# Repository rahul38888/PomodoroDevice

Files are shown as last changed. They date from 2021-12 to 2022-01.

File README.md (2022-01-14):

# PomodoroDevice

## 7 segments leds

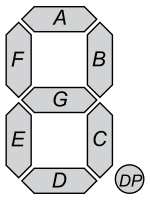
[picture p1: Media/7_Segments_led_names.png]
7 segments led names


## 4x7 segment display pinout diagram

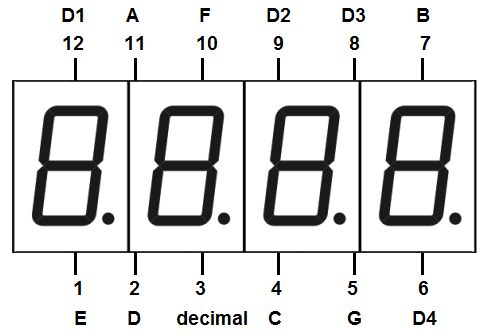
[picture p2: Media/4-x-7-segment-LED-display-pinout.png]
4x7 segment display pinout diagram


## Shift register 74HC595

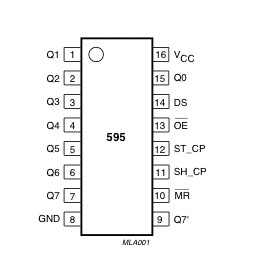
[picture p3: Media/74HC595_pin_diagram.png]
Shift register 74HC595


## Pins connections
| 4x7 pins | Arduino pins |
|-|-|
|D1 (Through 220 Ω)|2|
|D2 (Through 220 Ω)|3|
|D3 (Through 220 Ω)|4|
|D4 (Through 220 Ω)|5|

| 4x7 pins | 74HC595 pins |
|-|-|
|A|Q0|
|B|Q1|
|C|Q2|
|D|Q3|
|E|Q4|
|F|Q5|
|G|Q6|
|DP|Q7|

| Arduino pins | 74HC595 pins |
|-|-|
|GND|GND|
|5V|Vcc|
|11|DS|
|GND|OE|
|8|ST_CP|
|12|SH_CP|
|5V|MR|

## Bytes to Character mapping
|Character|Byte value (ABCDEFG)|Integer value|
|-|-|-|
|0|0000001|1|
|1|1001111|79|
|2|0010010|18|
|3|0000110|6|
|4|1001100|76|
|5|0100100|36|
|6|0100000|32|
|7|0001111|15|
|8|0000000|0|
|9|0000100|4|
|Blacnk|1111111|127|

1 means inactive and 0 means active.

**74HC595** need to have 8 bits written into it. The 1st place bit will decide state of **DP**. That is being added on runtime.

## Circuit diagrams
Schematics

## 3D plates

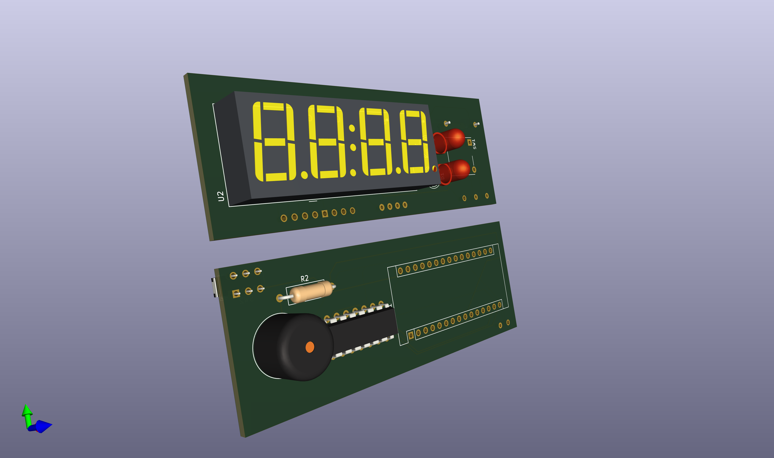
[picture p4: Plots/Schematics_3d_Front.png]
3D plates Front


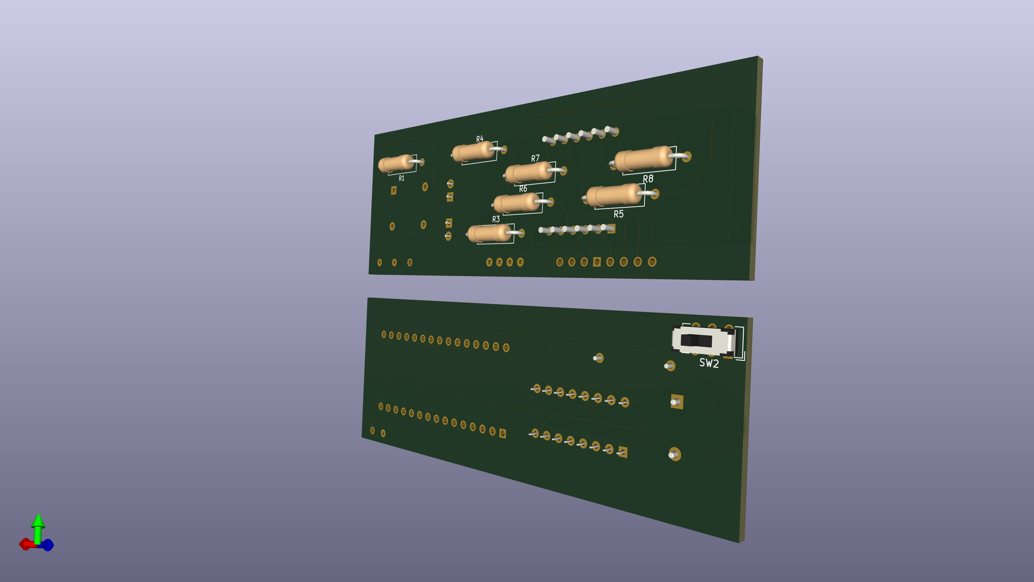
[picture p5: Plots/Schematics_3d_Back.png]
3D plates Back


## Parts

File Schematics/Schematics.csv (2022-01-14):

Source: | /Users/rpanchal/m_pro/Arduinos/PomodoroDevice/Schematics/Schematics.kicad_sch
Date: | 2022 January 02, Sunday 22:37:07
Tool: | Eeschema (6.0.0-0)
Generator: | /Applications/KiCad/KiCad.app/Contents/SharedSupport/plugins/bom_csv_grouped_by_value_with_fp.py
Component Count: | 15
Ref | Qnty | Value | Cmp name | Footprint | Description | Vendor
A1, | 1 | Arduino_Nano_v3.x | Arduino_Nano_v3.x | Module:Arduino_Nano | Arduino Nano v3.x
BZ1, | 1 | Buzzer | Buzzer | Buzzer_Beeper:Buzzer_12x9.5RM7.6 | Buzzer, polarized
D1, | 1 | Green LED | LED | LED_THT:LED_D5.0mm | Light emitting diode
D2, | 1 | Orange LED | LED | LED_THT:LED_D5.0mm | Light emitting diode
R1, R3, R4, R5, R6, R7, R8, | 7 | R 220 | R_Small | Resistor_THT:R_Axial_DIN0309_L9.0mm_D3.2mm_P12.70mm_Horizontal | Resistor, small symbol
R2, | 1 | R 100 | R_Small | Resistor_THT:R_Axial_DIN0309_L9.0mm_D3.2mm_P12.70mm_Horizontal | Resistor, small symbol
SW1, | 1 | SW_MEC_5E | SW_MEC_5E | Button_Switch_THT:SW_MEC_5GTH9 | MEC 5E single pole normally-open tactile switch
U1, | 1 | 74HC595 | 74HC595 | Package_DIP:DIP-16_W7.62mm | 8-bit serial in/out Shift Register 3-State Outputs
U2, | 1 | CC56-12YWA | CC56-12YWA | Display_7Segment:CC56-12YWA | 4 digit 7 segment yellow LED, common cathode

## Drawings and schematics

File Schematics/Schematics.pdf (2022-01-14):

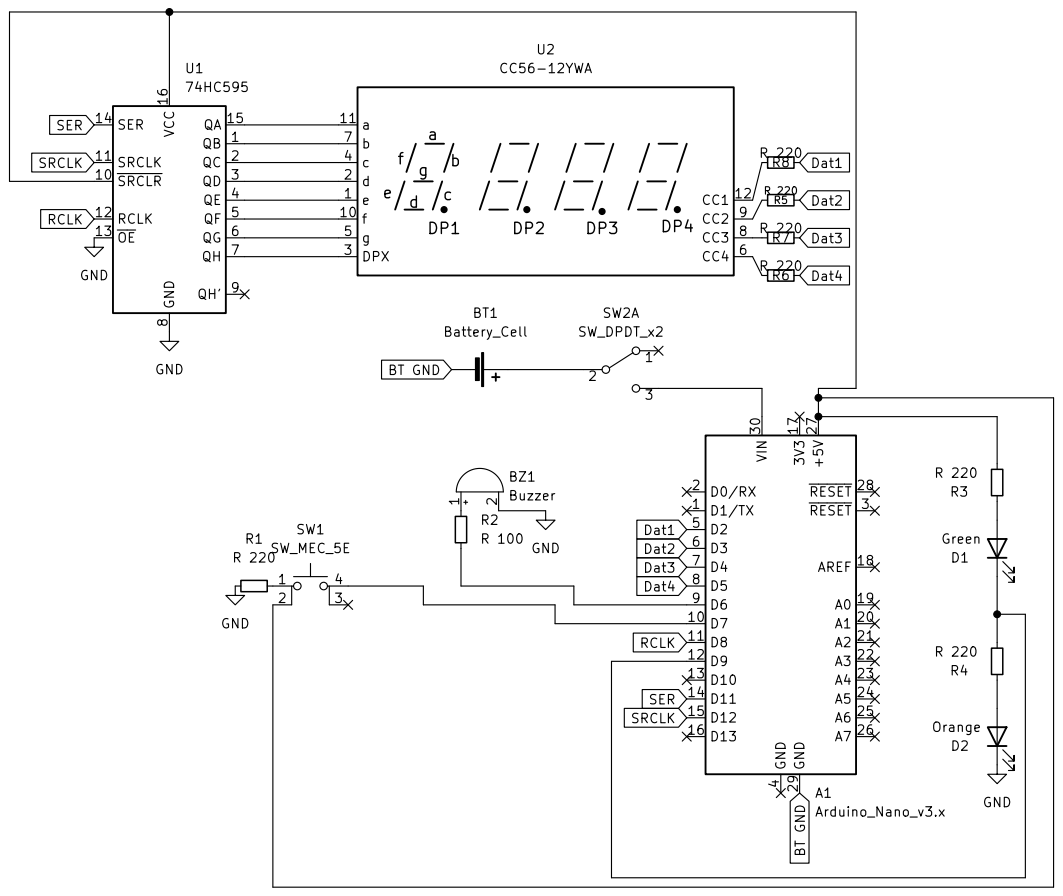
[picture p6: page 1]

File: Schematics.kicad_sch Sheet: / R1 R 220 GND

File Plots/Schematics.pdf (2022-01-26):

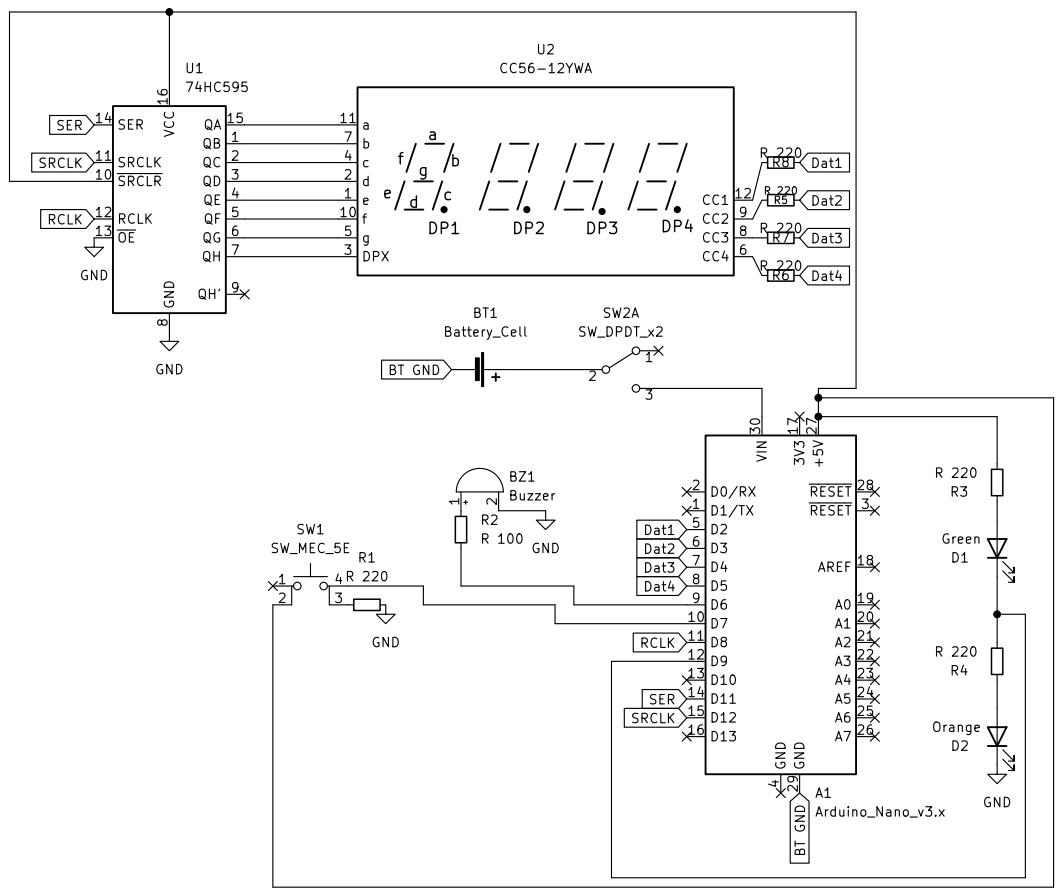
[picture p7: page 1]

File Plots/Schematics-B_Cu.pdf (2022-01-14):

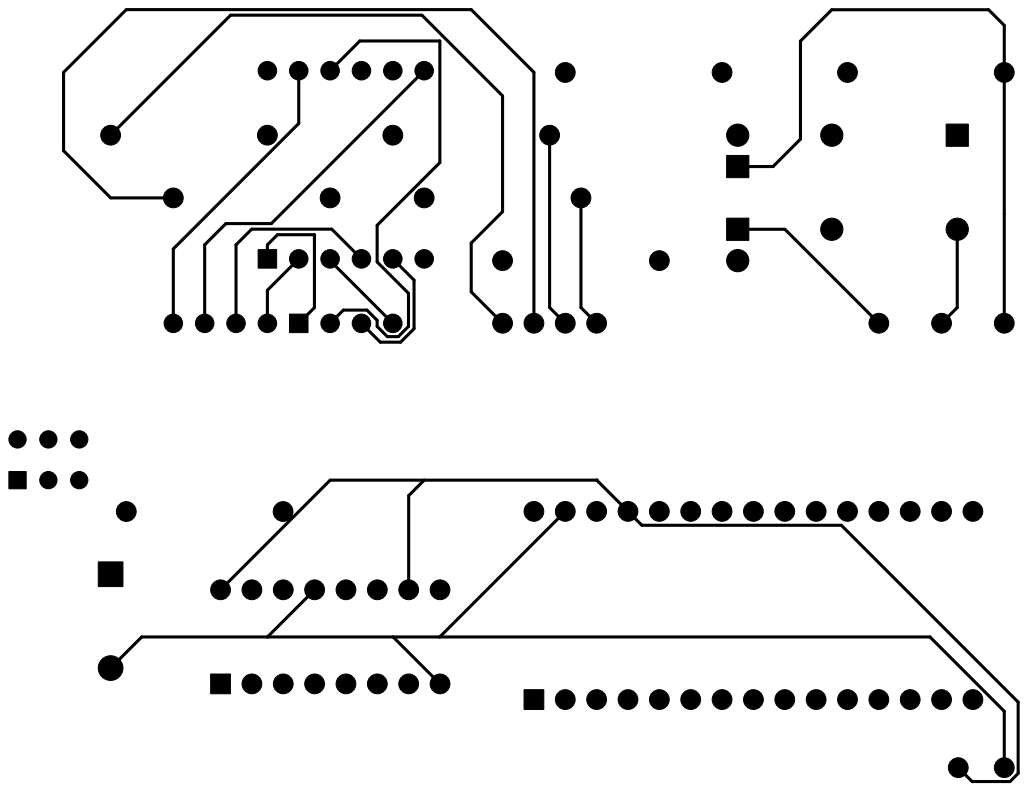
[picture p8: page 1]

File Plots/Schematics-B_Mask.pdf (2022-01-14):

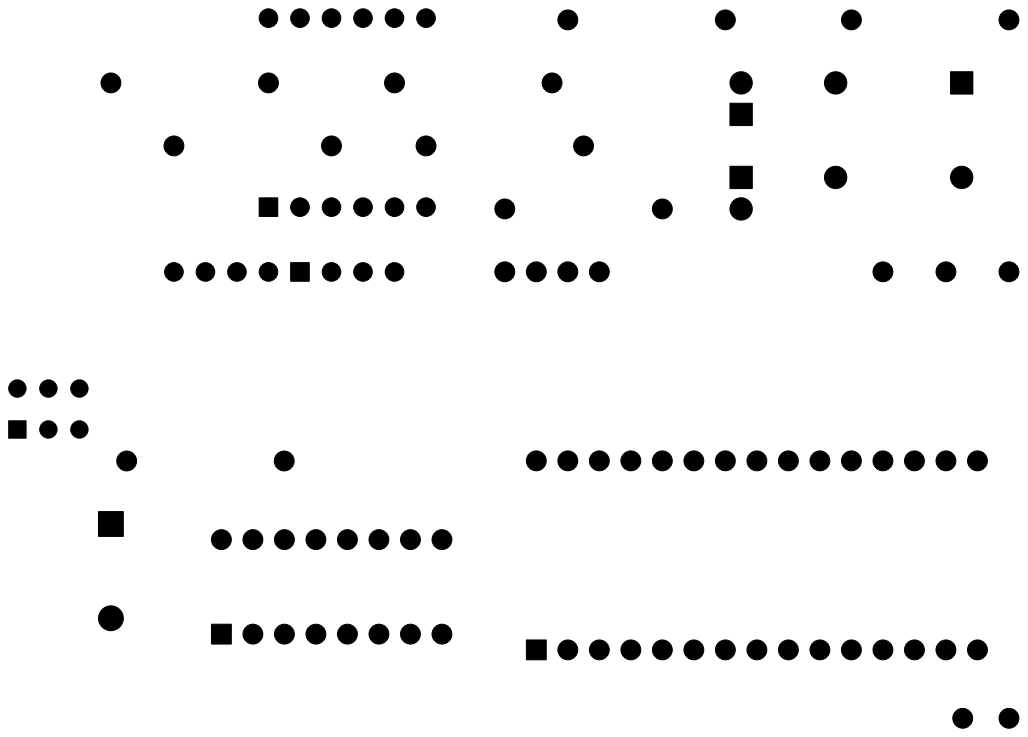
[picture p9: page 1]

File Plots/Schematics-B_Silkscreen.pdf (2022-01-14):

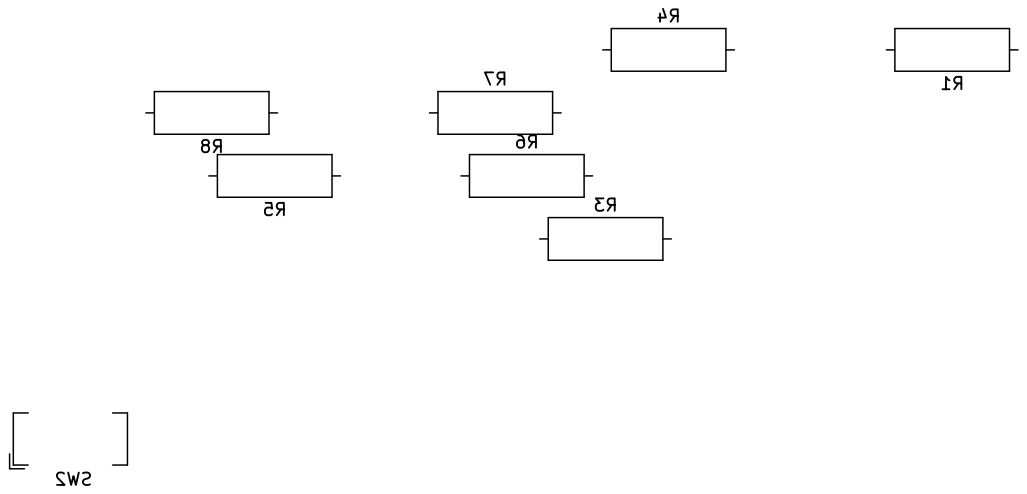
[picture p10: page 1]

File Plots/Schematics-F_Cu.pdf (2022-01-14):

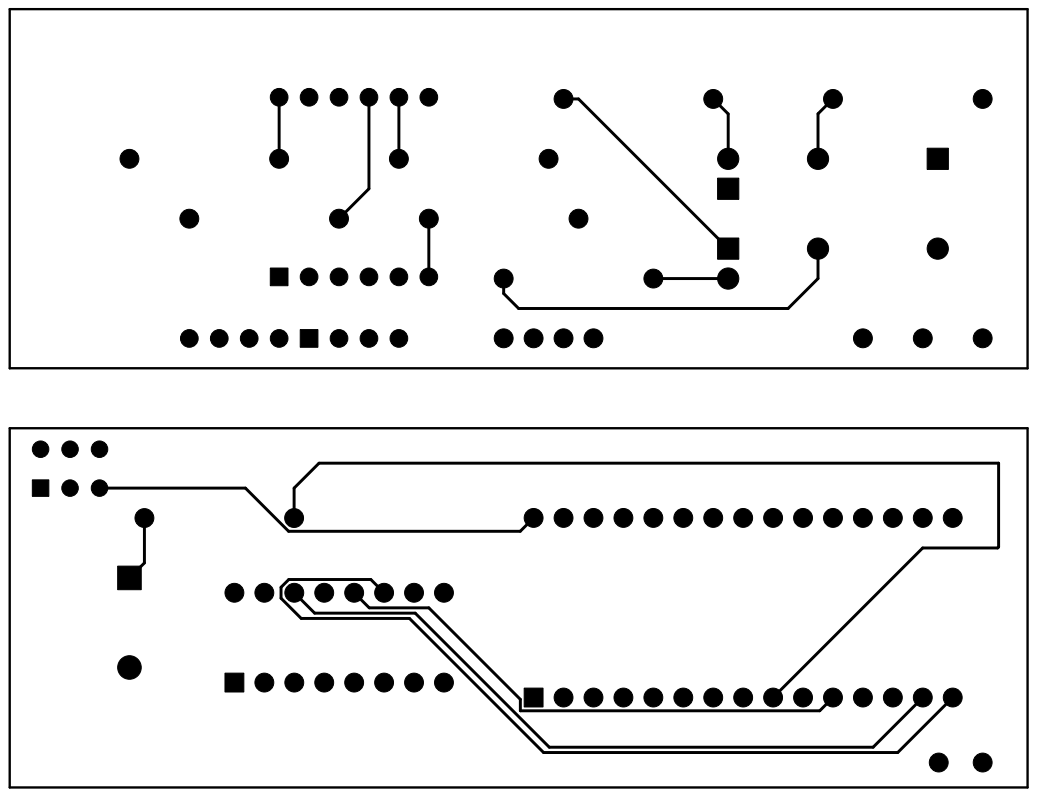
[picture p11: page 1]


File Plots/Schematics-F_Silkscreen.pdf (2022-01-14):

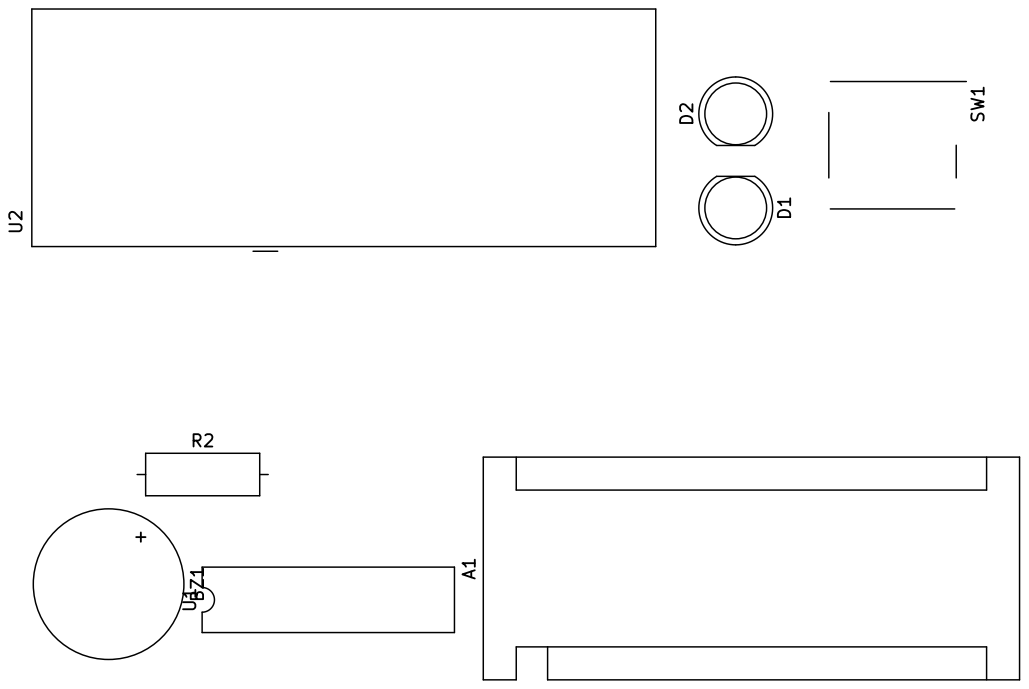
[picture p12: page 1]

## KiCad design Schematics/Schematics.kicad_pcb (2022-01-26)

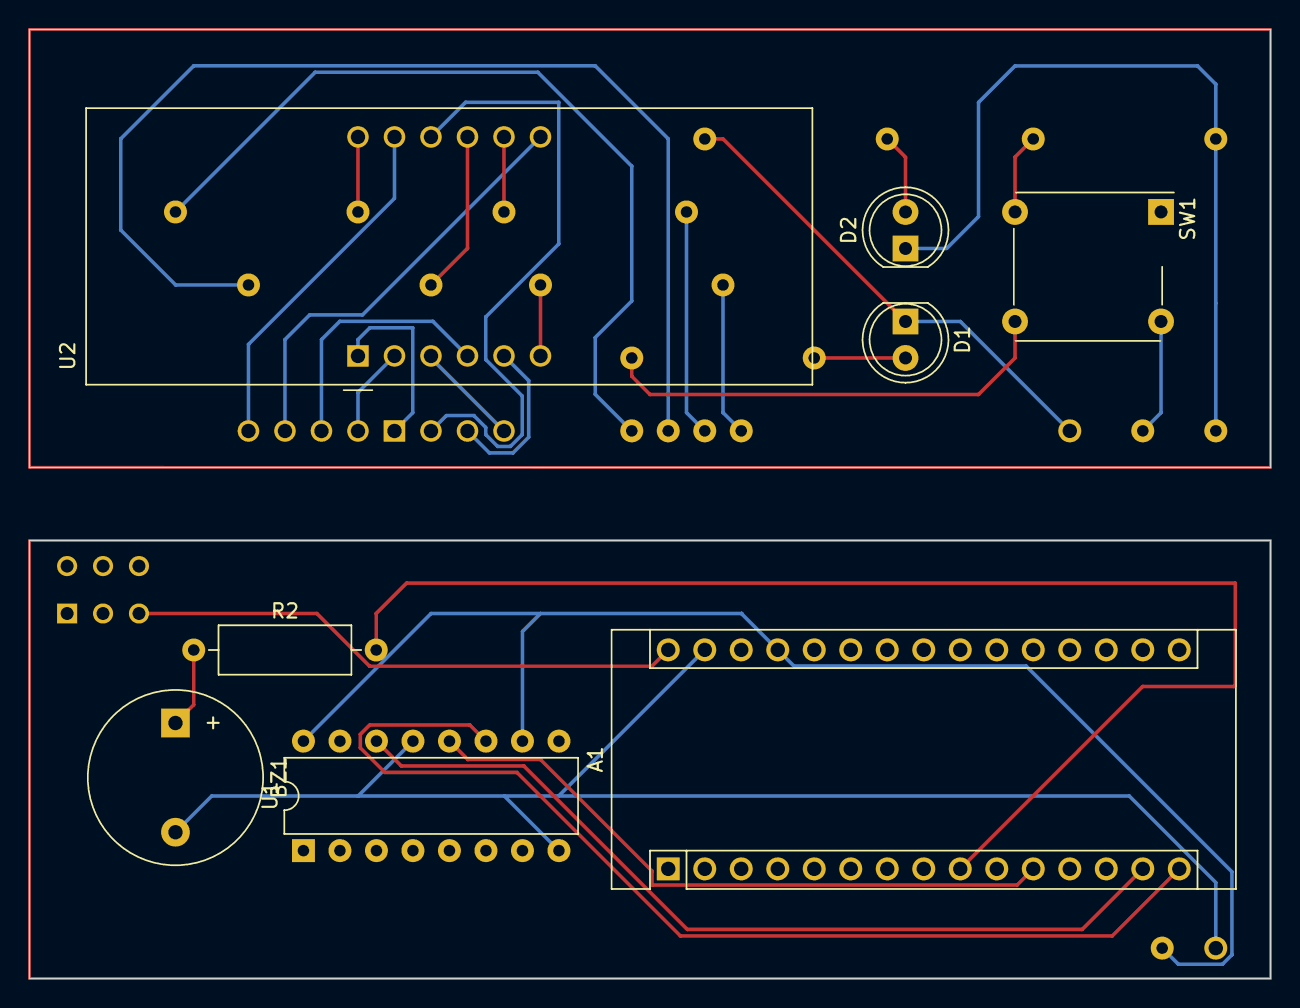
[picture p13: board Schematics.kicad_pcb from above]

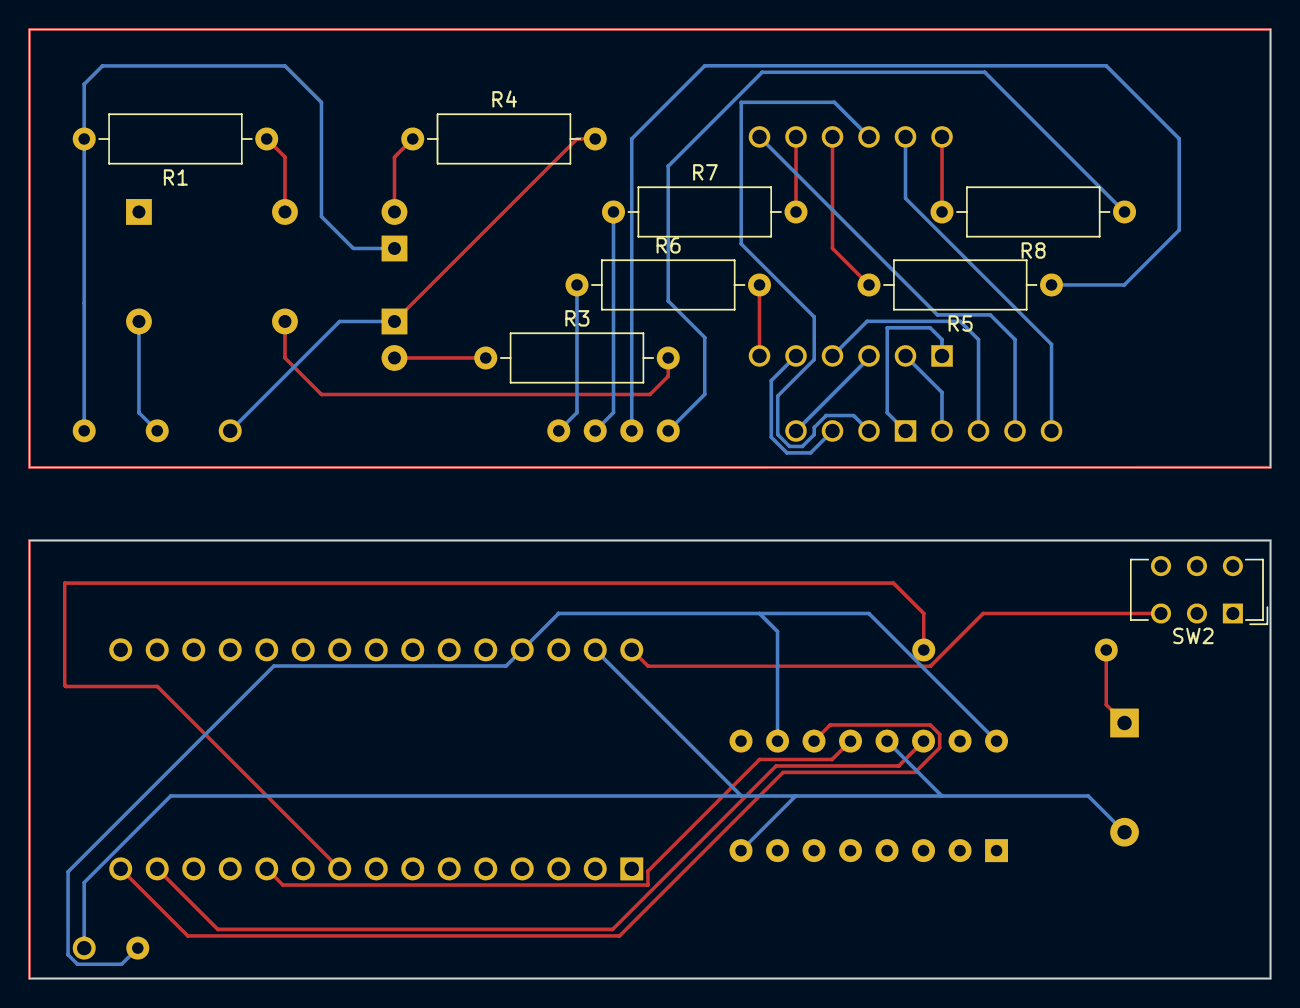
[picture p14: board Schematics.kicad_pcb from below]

Board: 2 copper layers, 86.4 x 66.0 mm, 16 parts (8 on the bottom side), 28 nets.

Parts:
A1: Arduino_Nano_v3.x; Arduino_Nano
BZ1: Buzzer; Buzzer_12x9.5RM7.6
D1: Green; LED_D5.0mm
D2: Orange; LED_D5.0mm
R1, R3, R4, R5, R6, R7, R8: R 220; R_Axial_DIN0309_L9.0mm_D3.2mm_P12.70mm_Horizontal
R2: R 100; R_Axial_DIN0309_L9.0mm_D3.2mm_P12.70mm_Horizontal
SW1: SW_MEC_5E; SW_MEC_5GTH9
SW2: SW_DPDT_x2; SW_CuK_JS202011CQN_DPDT_Straight
U1: 74HC595; DIP-16_W7.62mm
U2: CC56-12YWA

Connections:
Dat1: A1.5 (D2), R8.1
Dat2: A1.6 (D3), R5.1
Dat3: A1.7 (D4), R7.1
Dat4: A1.8 (D5), R6.1
GND: BZ1.2 (+), D2.1 (K), R1.2, U1.8 (GND), U1.13 (~OE)
unnamed: A1.9 (D6), R2.2
unnamed: A1.12 (D9), D1.1 (K), R4.2
unnamed: A1.27 (+5V), R3.2, SW1.2, U1.10 (~SRCLR), U1.16 (VCC)
unnamed: A1.30 (VIN), SW2.3 (C)
unnamed: BZ1.1 (-), R2.1
unnamed: D1.2 (A), R3.1
unnamed: D2.2 (A), R4.1
unnamed: R1.1, SW1.1
unnamed: R5.2, U2.9 (CC2)
unnamed: R6.2, U2.6 (CC4)
unnamed: R7.2, U2.8 (CC3)
unnamed: R8.2, U2.12 (CC1)
unnamed: U1.1 (QB), U2.7 (b)
unnamed: U1.2 (QC), U2.4 (c)
unnamed: U1.3 (QD), U2.2 (d)
unnamed: U1.4 (QE), U2.1 (e)
unnamed: U1.5 (QF), U2.10 (f)
unnamed: U1.6 (QG), U2.5 (g)
unnamed: U1.7 (QH), U2.3 (DPX)
unnamed: U1.15 (QA), U2.11 (a)
RCLK: A1.11 (D8), U1.12 (RCLK)
SER: A1.14 (D11), U1.14 (SER)
SRCLK: A1.15 (D12), U1.11 (SRCLK)

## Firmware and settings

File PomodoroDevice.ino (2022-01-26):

int D1 = 2;
int D2 = 3;
int D3 = 4;
int D4 = 5;

int dataPin = 11;
int latchPin = 8;
int clockPin = 12;

int buzzerPin = 6;

int buttonPin = 7;

int stateLedPin = 9;

// ----- ^^ PINS ^^ -----

int delayTime = 4;
int buzzerFrequency = 523;

int nums[10] = {
  1, 79, 18, 6, 76, 36, 32, 15, 0, 4
};
int blanckNum = 127;
int pLetter = 24;

void updateShiftRegisterState(byte input){
  digitalWrite(latchPin, LOW);
  shiftOut(dataPin, clockPin, LSBFIRST, input);
  digitalWrite(latchPin, HIGH);
}

void draw(int state, bool enableDecimal){
  int leds = state*2;
  if(!enableDecimal) {
    leds = leds + 1;
  }
  
  updateShiftRegisterState(leds);
}

void resetTo(int letter, int dState){
  digitalWrite(D1, dState);
  digitalWrite(D2, dState);
  digitalWrite(D3, dState);
  digitalWrite(D4, dState);
  
  draw(letter, false);
}

void setDigit(int d1, int d2, int d3, int d4){
  digitalWrite(D1, d1);
  digitalWrite(D2, d2);
  digitalWrite(D3, d3);
  digitalWrite(D4, d4);
}

void setD1() {
  setDigit(HIGH, LOW, LOW, LOW);
}

void setD2() {
  setDigit(LOW, HIGH, LOW, LOW);
}

void setD3() {
  setDigit(LOW, LOW, HIGH, LOW);
}

void setD4() {
  setDigit(LOW, LOW, LOW, HIGH);
}

void drawNumber(int num){
  if(num == -1){
    resetTo(blanckNum, LOW);
    return;
  }
  else if(num == -2){
    resetTo(pLetter, HIGH);
    return;
  }

  for(int i=0; i<4; i++){
    if(num==0 and i>0){
      break;
    }
    
    int dig = num % 10;
    num = num/10;
    
    if(i==0){
      setD4();
    }
    else if(i==1){
      setD3();
    }
    else if(i==2){
      setD2();
    }
    else if(i==3){
      setD1();
    }
    bool enableDecimal = false;
    if(i==2){
      enableDecimal = true;
    }
    draw(nums[dig], enableDecimal);
    delay(delayTime);
    resetTo(blanckNum, LOW);
  }
}

int secToTime(int secs){
  int mins = secs/60;
  int remSecs = secs%60;

  return mins*100 + remSecs;
}

int pomodoroSecs[8] = {
  1500, 300, 1500, 300, 1500, 300, 1500, 900
};
//int pomodoroSecs[8] = {
//  10, 5, 10, 5, 10, 5, 10, 6
//};

bool isWorkState[8] = {
  true, false, true, false, true, false, true, false
};

int curPomodoro = 0;

int curSecs = -1;

int STOP_SIGNAL = -2;
int WELCOME_STATE = -1;
int TIMER_STATE = 0;
int TIMER_END = 1;
int TIMER_PAUSED = 2;
int SKIP_SIGNAL = 3;

int deviceState = WELCOME_STATE;

void resetTimer(){
  curSecs = 0;
  curPomodoro = (curPomodoro+1)%8;
}

unsigned long nextMillis = 0;

int setNextMillis(int gap){
    nextMillis = millis()+gap;
    nextMillis = nextMillis - nextMillis%100;
}

int lastButtonState = LOW;
int curButtonState;
unsigned long debounceDelay = 50;
unsigned long lastDebounceTime  = 0;
unsigned long buttonDownMillis = 0;

unsigned long longPressTime = 1000;
unsigned long stopPressTime = 3000;

unsigned long isButtonPressed(){
  unsigned long pressTime = 0;
  
  int buttonState = digitalRead(buttonPin);

  if(lastButtonState != buttonState)
    lastDebounceTime = millis();

  if((millis() - lastDebounceTime) > debounceDelay)
    if(buttonState != curButtonState){
      curButtonState = buttonState;
      
      if(curButtonState == HIGH)
         buttonDownMillis = millis();
      if(curButtonState == LOW)
        pressTime = millis() - buttonDownMillis;
    }

  lastButtonState = buttonState;
  return pressTime;
}

bool disOn = true;

void resetDevice(){
  curSecs = -1;
  curPomodoro = 0;
}

int timerPaused(){
  unsigned long buttonMillis = isButtonPressed();
  if(buttonMillis>stopPressTime){
    drawNumber(-1);
    noTone(buzzerPin);
    resetDevice();
    return STOP_SIGNAL;
  }
  else if(buttonMillis>longPressTime)
    return SKIP_SIGNAL;
  else if(buttonMillis)
    return TIMER_STATE;
  
  if(millis() > nextMillis){
    setNextMillis(500);
    disOn = !disOn;
  }

  if(disOn)
    drawNumber(secToTime(curSecs));
  else
    drawNumber(-1);

  return TIMER_PAUSED;

}

int timerRunner(){

  unsigned long buttonMillis = isButtonPressed();
  if(buttonMillis>stopPressTime){
    drawNumber(-1);
    noTone(buzzerPin);
    resetDevice();
    return STOP_SIGNAL;
  }
  else if(buttonMillis>longPressTime)
    return SKIP_SIGNAL;
  else if(buttonMillis) {
    tone(buzzerPin, buzzerFrequency);
    noTone(buzzerPin);
    return TIMER_PAUSED;
  }
  
  if(curSecs <= pomodoroSecs[curPomodoro]){
    if(millis() > nextMillis){
      curSecs++;
      setNextMillis(1000);
    }

    digitalWrite(stateLedPin, isWorkState[curPomodoro]);
    
    drawNumber(secToTime(curSecs));
    return TIMER_STATE;
  }
  else{
    resetTimer();
    return TIMER_END;
  }
}

int timerEnderProgramm(){
  unsigned long buttonMillis = isButtonPressed();
  if(buttonMillis>stopPressTime){
    drawNumber(-1);
    noTone(buzzerPin);
    resetDevice();
    return STOP_SIGNAL;
  }
  else if(buttonMillis > longPressTime)
    return SKIP_SIGNAL;
  else if(buttonMillis){
    noTone(buzzerPin);
    return TIMER_STATE;
  }
  
  digitalWrite(stateLedPin, isWorkState[curPomodoro]);

  if(millis() > nextMillis){
    setNextMillis(500);
    disOn = !disOn;
  }

  if(disOn){
    drawNumber(secToTime(pomodoroSecs[curPomodoro]));
    tone(buzzerPin, buzzerFrequency);
  }
  else{
    drawNumber(-1);
    noTone(buzzerPin);
  }
  return TIMER_END;
}

int skipCurrentTimer(){
    resetTimer();
    return TIMER_END;
}


unsigned long welcomeTomeLength = 2000;
unsigned long startMillis = 0;
int welcomeProgramm(){
  if(millis()-startMillis<=welcomeTomeLength){
    tone(buzzerPin, buzzerFrequency);
  }
  else
    noTone(buzzerPin);
  
  unsigned long buttonMillis = isButtonPressed();
  if(buttonMillis>stopPressTime){
    drawNumber(-1);
    noTone(buzzerPin);
    resetDevice();
    return STOP_SIGNAL;
  }
  else if(buttonMillis){
    pinMode(stateLedPin, OUTPUT);
    noTone(buzzerPin);
    return TIMER_STATE;
  }
  
  drawNumber(-2);
  return WELCOME_STATE;
}

int doNothing(){
  pinMode(stateLedPin, INPUT);
  if(isButtonPressed()){
    startMillis = millis();
    return WELCOME_STATE;
  }

  return STOP_SIGNAL;
}

void setup() {
  pinMode(D1, OUTPUT);
  pinMode(D2, OUTPUT);
  pinMode(D3, OUTPUT);
  pinMode(D4, OUTPUT);
  
  pinMode(dataPin, OUTPUT);
  pinMode(latchPin, OUTPUT);
  pinMode(clockPin, OUTPUT);

  pinMode(buzzerPin, OUTPUT);

  pinMode(buttonPin, INPUT);

  pinMode(stateLedPin, INPUT);
}

void loop() {
  if(deviceState == STOP_SIGNAL)
    deviceState = doNothing();
  else if(deviceState == WELCOME_STATE)
    deviceState = welcomeProgramm();
  else if(deviceState == TIMER_STATE)
    deviceState = timerRunner();
  else if(deviceState == TIMER_PAUSED)
    deviceState = timerPaused();
  else if(deviceState == TIMER_END)
    deviceState = timerEnderProgramm();
  else if(deviceState == SKIP_SIGNAL)
    deviceState = skipCurrentTimer();
  
}

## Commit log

2021-12-28 Timer + ender programm working. Without buttons and buzzer
    [PomodoroDevice.ino]
2021-12-29 Working: Buzzer, Button, Pomodoro sequance, IsWorking status with 2 leds
    [PomodoroDevice.ino]
2022-01-01 Schematics using KiCad
    [Schematics.kicad_pcb, Schematics.kicad_sch]
2022-01-14 Final Kicad changes
    [Schematics.csv, Schematics.kicad_pcb, Schematics.kicad_sch]
2022-01-26 new fucntion in device
    [Schematics-B_Cu.gbr, Schematics-B_Mask.gbr, Schematics-B_Paste.gbr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]
